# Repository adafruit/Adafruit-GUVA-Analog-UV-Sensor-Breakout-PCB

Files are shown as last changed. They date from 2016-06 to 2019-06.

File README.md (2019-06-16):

# Adafruit-GUVA-Analog-UV-Sensor-Breakout-PCB

__Format is EagleCAD schematic and board layout__

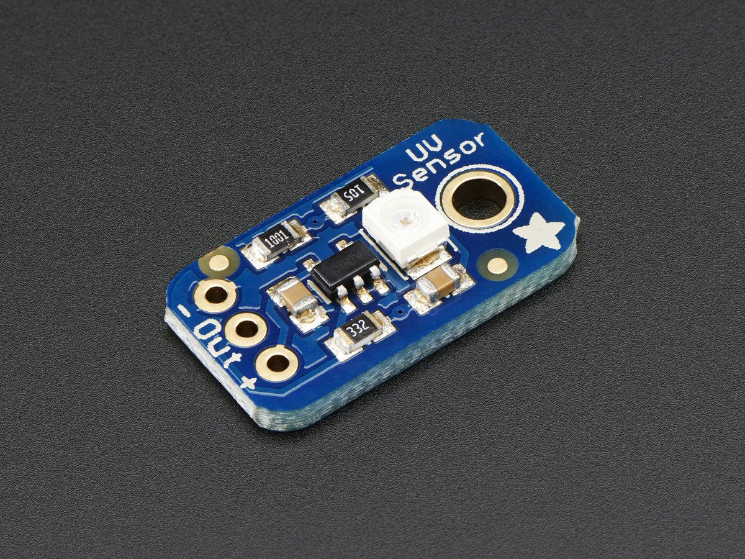
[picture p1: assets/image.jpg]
<a href="http://www.adafruit.com/products/1918"><br/>Click here to purchase one from the Adafruit shop</a>

Extend your light-sensing spectrum with this analog UV sensor module. It uses a UV photodiode, which can detect the 240-370nm range of light (which covers UVB and most of UVA spectrum). The signal level from the photodiode is very small, in the nano-ampere level, so we tossed on an opamp to amplify the signal to a more manageable volt-level.

This sensor is much simpler than our Si1145 breakout, it only does one thing and gives an analog voltage output instead of requiring a complicated I2C setup procedure. This makes it better for simple projects. It also has a 'true' UV sensor instead of a calibrated light-sensor. To use, power the sensor and op-amp by connecting V+ to 2.7-5.5VDC and GND to power ground. Then read the analog signal from the OUT pin. The output voltage is: Vo = 4.3 * Diode-Current-in-uA. So if the photocurrent is 1uA (9 mW/cm^2), the output voltage is 4.3V. You can also convert the voltage to UV Index by dividing the output voltage by 0.1V. So if the output voltage is 0.5V, the UV Index is about 5.

Please note, our UV LEDs are 400nm, outside the range of this sensor, so if you're trying to test this sensor, don't use them! A UV tanning lamp or 'lizard-lamp' will work much better.

## License

Adafruit invests time and resources providing this open source design, 
please support Adafruit and open-source hardware by purchasing 
products from Adafruit!

Designed by Adafruit Industries.  
Creative Commons Attribution, Share-Alike license, check license.txt for more information
All text above must be included in any redistribution

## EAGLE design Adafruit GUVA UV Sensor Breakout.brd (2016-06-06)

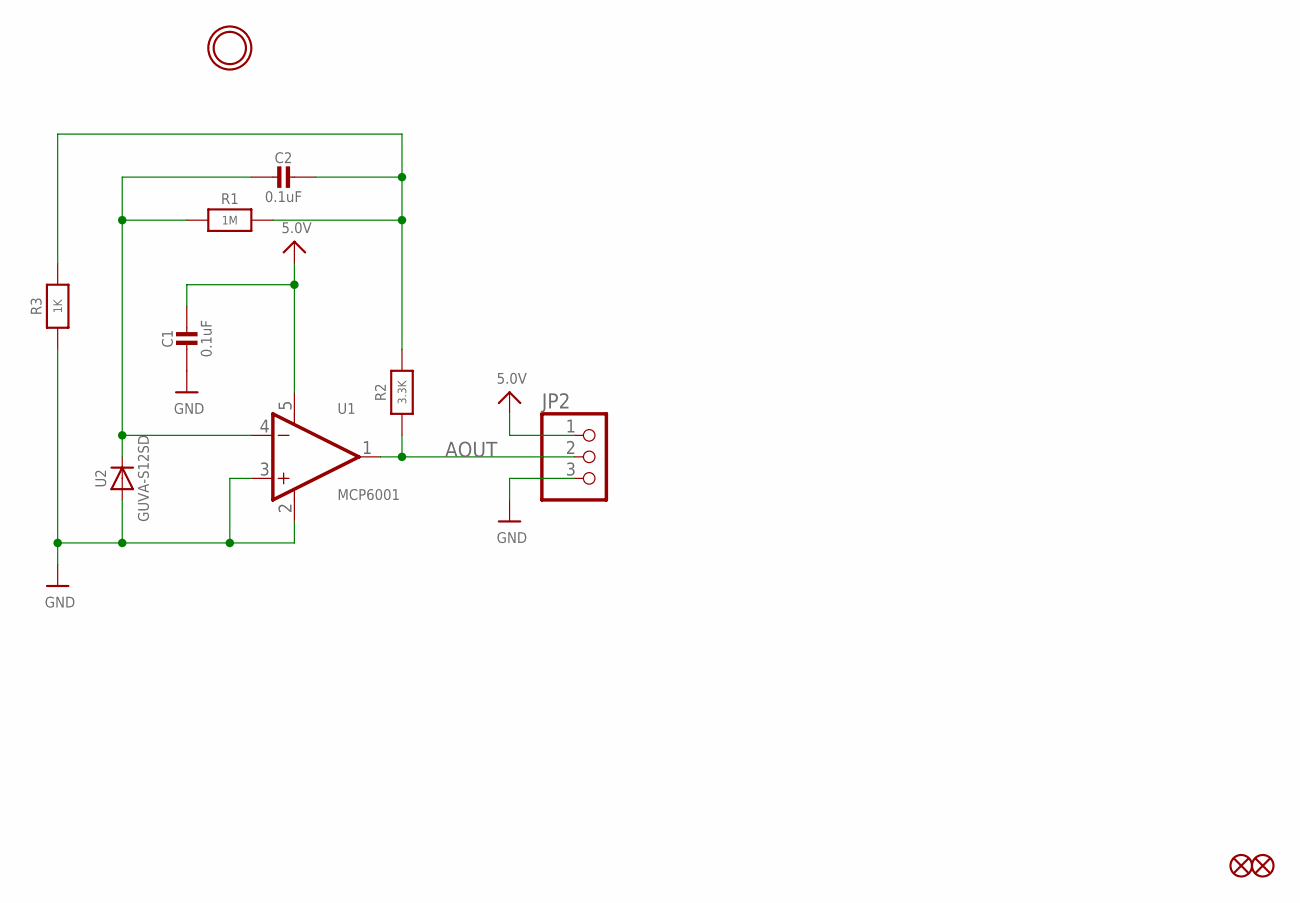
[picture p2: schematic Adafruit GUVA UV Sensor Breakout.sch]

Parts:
C1, C2: 0.1uF; 0805-NO
FID1, FID2: FIDUCIAL""; FIDUCIAL_1MM
JP2: PINHD-1X3CB; 1X03-CLEANBIG
R1: 1M; 0805-NO
R2: 3.3K; 0805-NO
R3: 1K; 0805-NO
U1: MCP6001; SOT23-5
U2: GUVA-S12SD
U$6: MOUNTINGHOLE2.5; MOUNTINGHOLE_2.5_PLATED

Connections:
5.0V: C1.1, JP2.1, U1.5 (V+)
AOUT: JP2.2, R2.1, U1.1 (OUT)
GND: C1.2, JP2.3, R3.1, U1.2 (V-), U1.3 (+IN), U2.A
unnamed: C2.1, R1.2, R2.2, R3.2
unnamed: C2.2, R1.1, U1.4 (-IN), U2.K (C)

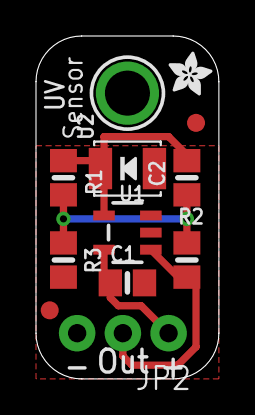
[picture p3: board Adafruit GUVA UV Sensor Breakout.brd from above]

Board: 2 copper layers, 10.2 x 19.1 mm, 13 parts (1 on the bottom side), 5 nets.

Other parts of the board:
U$7, U$8: ADAFRUIT_2.5MM

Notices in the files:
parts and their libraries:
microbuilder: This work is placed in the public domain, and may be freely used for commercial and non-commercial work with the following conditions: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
